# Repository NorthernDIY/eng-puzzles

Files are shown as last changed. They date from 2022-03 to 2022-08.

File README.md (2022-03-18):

# eng-puzzles
## ECE4600 G15 2021/2022 Capstone Project Code & Design Files
**As prepared by: Rowen Guncheon, Nicolas Hince, David Stewart, Lin Zhan on March 18/2022**

**For details of the software requirements for a particular portion of the project, please see the README.md file in the associated folder.**

# Summary of Hardware directory contents:
- **Hardware/MazeUnit**:  STL files for 3D printing a completed maze unit (with ESP32 Sidecar)
- **Hardware/PCB/ESP32_Subsystem**: PCB design files for the ESP32 Subsystem board that sits in the sidecar adjacent to the maze unit.
- **Hardware/PCB/POC**: PCB Design files for the Proof Of Concept board featuring ALS31313 Sensors
- **Hardware/PCB/Sensor_Block**:  PCB design files for the modular (2x2) Hall sensor boards that sit beneath the maze floor.
- **Hardware/Stylus**:  STL files for 3D printing a stylus unit.

# Summary of Software directory contents:
- **Software/AllPaths**:  Algorithm used for generating a library of paths from a given input maze.  (For use with future machine learning work)
- **Software/Main_Firmware**:  The main firmware that runs on the ESP32 SOC within the Maze Unit.
- **Software/PacketSimulator**: Python application that emulates ESP32 data packet format (Used during development)
- **Software/Addressing_Firmware**:  The initial Hall sensor address programming firmware that runs on the ESP32 SOC.
- **Software/Server**:  The required Python/Flask based server that runs on the Raspberry Pi (or other Linux system)
- **Software/Visualization**: The data visualization php script that reads data from the SQL database and overlays this information on a web page.  (place in /var/www/html)

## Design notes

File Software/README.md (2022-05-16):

# eng-puzzles
##Serious Games - Summer Research 2022
**by David Stewart**

**For details of the software requirements for a particular portion of the project, please see the README.md file in the associated folder.**
# Summary of Software directory contents:
- **Addressing_Firmware**:  The initial Hall sensor address programming firmware that runs on the ESP32 SOC.
- **PacketSimulator**: Python application that emulates ESP32 data packet format (Used during development)
- **Server**:  Python/Flask based server that runs on the Raspberry Pi (or other Linux system) and processing incoming data from the Maze Unit
- **Visualization**: The data visualization php script that reads data from the SQL database and overlays this information on a web page.  (place in /var/www/html)
- **Archive**: Older versions of code.
- - **AllPaths**:  Algorithm used for generating a library of paths from a given input maze.  (For use with future machine learning work)
- - **Main_Firmware**:  The main firmware that runs on the ESP32 SOC within the Maze Unit.

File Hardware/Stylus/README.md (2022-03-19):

# eng-puzzles
## ECE4600 G15 2021/2022 Capstone Project Code & Design Files
**As prepared by: Rowen Guncheon, Nicolas Hince, David Stewart, Lin Zhan on March 18/2022**

## Stylus STL Parts Info

### Software Used
- AutoDesk Inventor
- AutoDesk Print Studio

### Units
- Inches

### Parts Included
- Stylus main
- Stylus cap
- Stylus Insert

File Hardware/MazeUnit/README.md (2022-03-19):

# eng-puzzles
## ECE4600 G15 2021/2022 Capstone Project Code & Design Files
**As prepared by: Rowen Guncheon, Nicolas Hince, David Stewart, Lin Zhan on March 18/2022**

## Maze Unit STL Parts Info

### Software Used
- AutoDesk Inventor
- AutoDesk Print Studio

### Units
- Inches

### Parts Included
- Maze side A
- Maze side B
- Floor side A
- Floor side B
- Sidecar
- Sidecar cap

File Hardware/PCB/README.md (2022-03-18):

# eng-puzzles
## ECE4600 G15 2021/2022 Capstone Project Code & Design Files
**As prepared by: Rowen Guncheon, Nicolas Hince, David Stewart, Lin Zhan on March 18/2022**
## Hardware/PCB
- **ESP32_Subsystem**: PCB design files for the ESP32 Subsystem board that sits in the sidecar adjacent to the maze unit.
- **POC**: PCB Design files for the Proof Of Concept board featuring ALS31313 Sensors
- **Sensor_Block**:  PCB design files for the modular (2x2) Hall sensor boards that sit beneath the maze floor.

### Required Software
These files were exported from EasyEDA V 6.4.31 and should be importable to later versions.

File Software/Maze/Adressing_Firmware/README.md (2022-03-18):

# eng-puzzles
## ECE4600 G15 2021/2022 Capstone Project Code & Design Files
**As prepared by: Rowen Guncheon, Nicolas Hince, David Stewart, Lin Zhan on March 18/2022**

# Addressing_Firmware:
  The initial Hall sensor address programming firmware that runs on the ESP32 SOC.
  ### ***This must be run before uploading the main firmware file.***

## Requires:
- Arduino IDE v1.18 or newer

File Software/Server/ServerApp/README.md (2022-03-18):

# eng-puzzles
## ECE4600 G15 2021/2022 Capstone Project Code & Design Files
**As prepared by: Rowen Guncheon, Nicolas Hince, David Stewart, Lin Zhan on March 18/2022**

# Server:
Python/Flask based server that runs on the Raspberry Pi (or other Linux system) and processing incoming data from the Maze Unit. Contains both acceleromter filtering and the full positioning system.

This is basically glue that combines project elements.

## Requires:
- Python 3.7
- - With the following libraries: numpy, pymysql, scipy, flask, colorama, csv, math, time, os, json, sys

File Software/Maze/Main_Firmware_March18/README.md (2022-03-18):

# eng-puzzles
## ECE4600 G15 2021/2022 Capstone Project Code & Design Files
**As prepared by: Rowen Guncheon, Nicolas Hince, David Stewart, Lin Zhan on March 18/2022**

# Main_Firmware:  The main firmware that runs on the ESP32 SOC within the Maze Unit.

## Requires:
- Visual Studio Code:
  - With PlatformIO plugin installed
    - With ESP32 Board support package installed

- Libraries & Frameworks:
  - arduino-esp32 (https://github.com/espressif/arduino-esp32): Enables arduino framework to run on the ESP32 SOC.
  - ArduinoJSON (https://github.com/bblanchon/ArduinoJson): Enables serialization of data to JSON format.
  - SparkFun LIS2DH12 Arduino Library (https://github.com/sparkfun/SparkFun_LIS2DH12_Arduino_Library):  Provides support for the LIS2DH12 accelerometer.

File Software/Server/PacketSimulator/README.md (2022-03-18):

# eng-puzzles
## ECE4600 G15 2021/2022 Capstone Project Code & Design Files
**As prepared by: Rowen Guncheon, Nicolas Hince, David Stewart, Lin Zhan on March 18/2022**

# PacketSimulator:
Python application that emulates ESP32 data packet format (Used during development)

## Requires:
- Python 3.7
- - With the following libraries: json, random, requests, sys, datetime

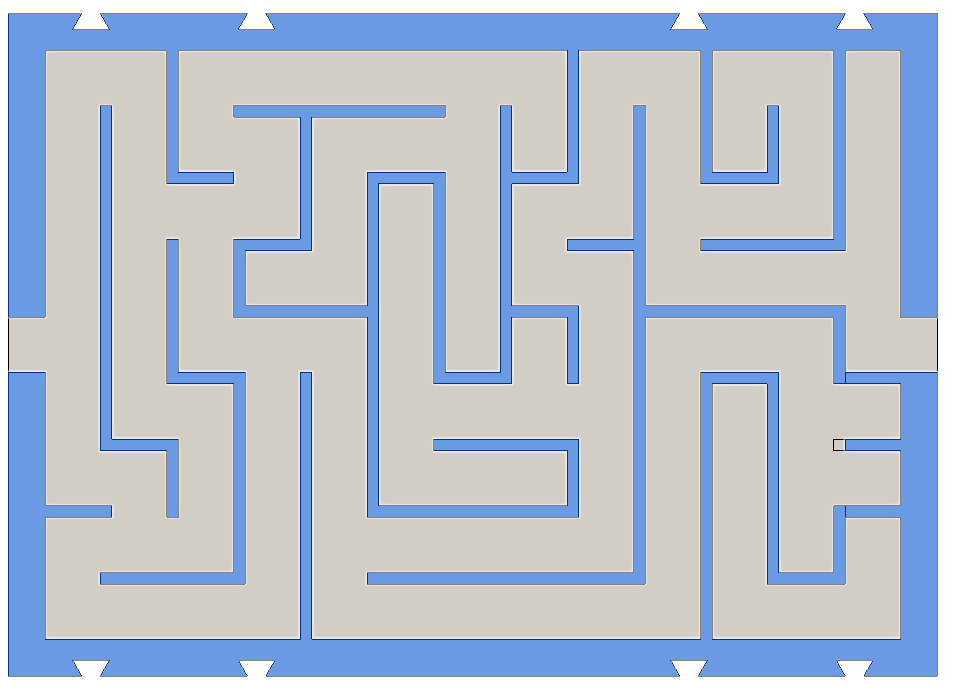
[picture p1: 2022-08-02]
Software/Server/ServerApp/Maze_top_down.png

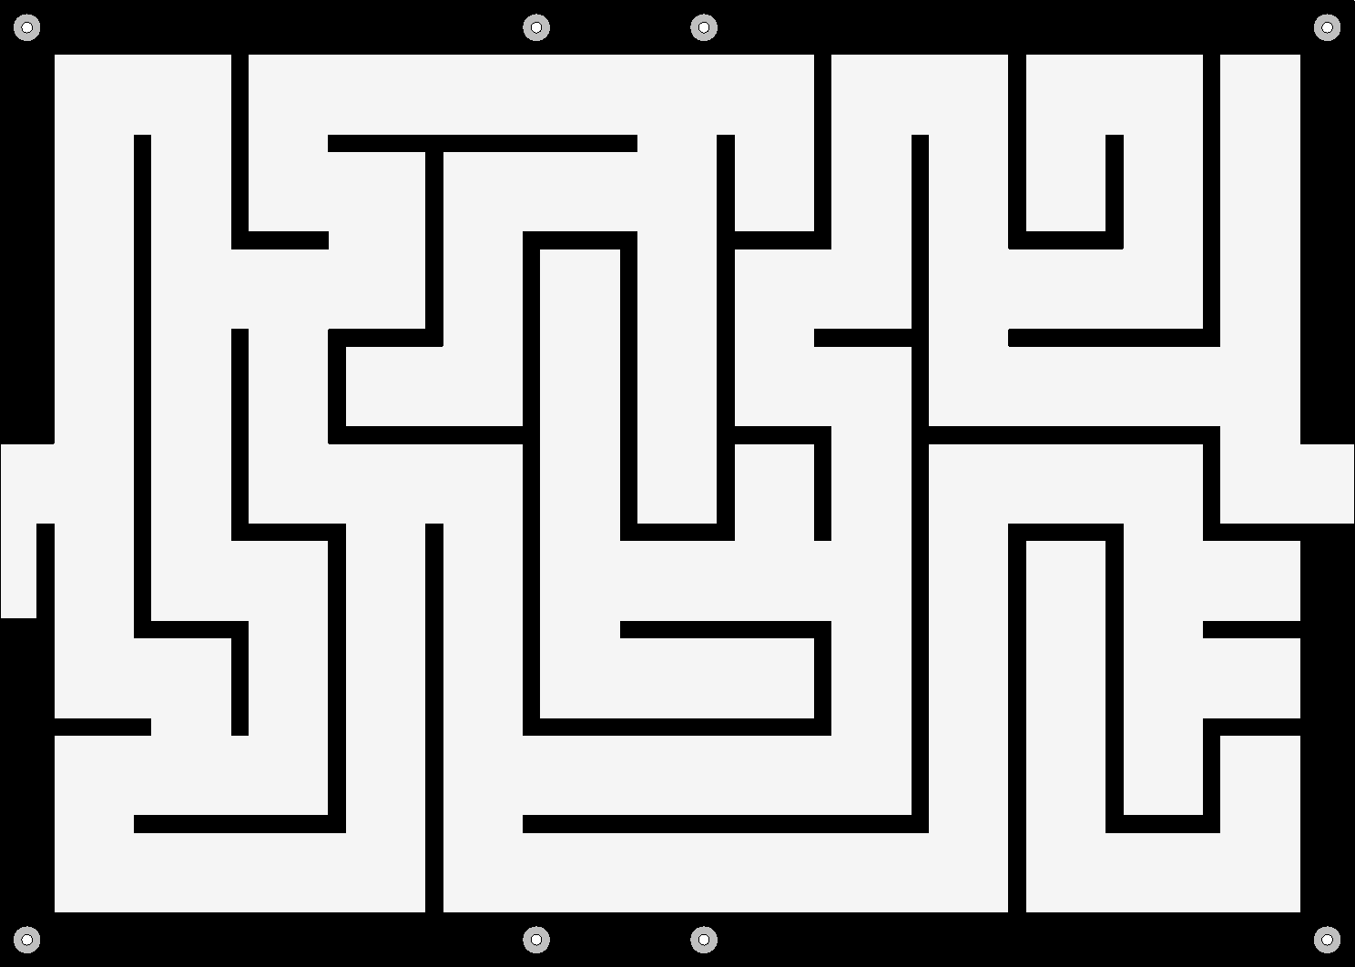
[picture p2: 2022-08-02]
Software/Server/ServerApp/MazeBWG.png

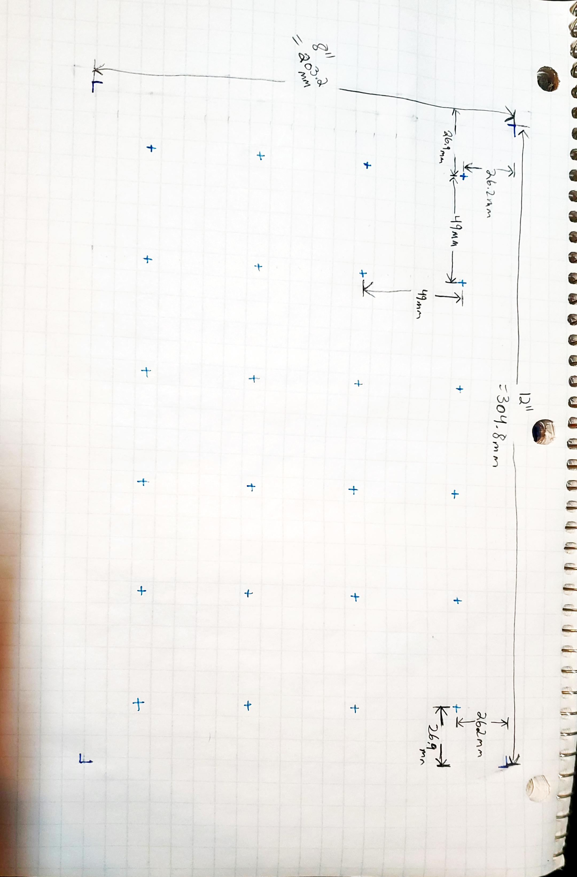
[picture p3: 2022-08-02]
Software/Server/ServerApp/MAzeSpacing.jpg

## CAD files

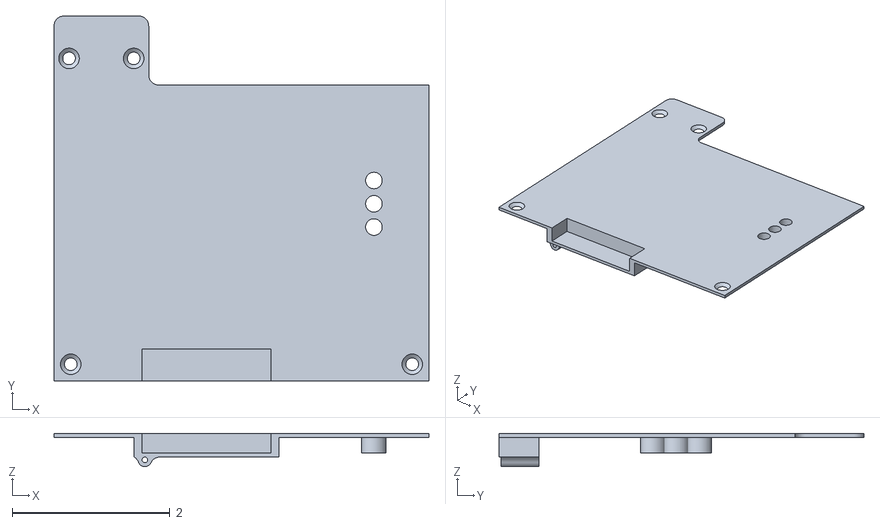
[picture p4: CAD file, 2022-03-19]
Hardware/MazeUnit/Sidecar Cap.stl
4.75 x 4.62 x 0.422

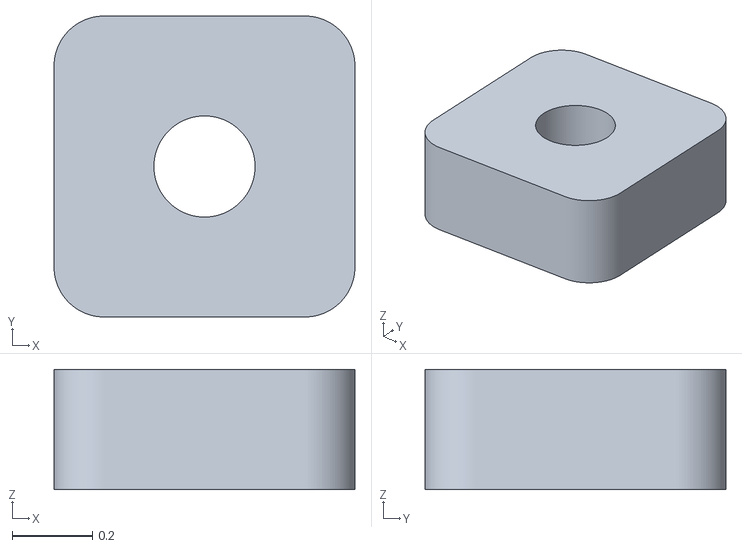
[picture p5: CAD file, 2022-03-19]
Hardware/Stylus/Stylus insert.stl
0.75 x 0.75 x 0.3

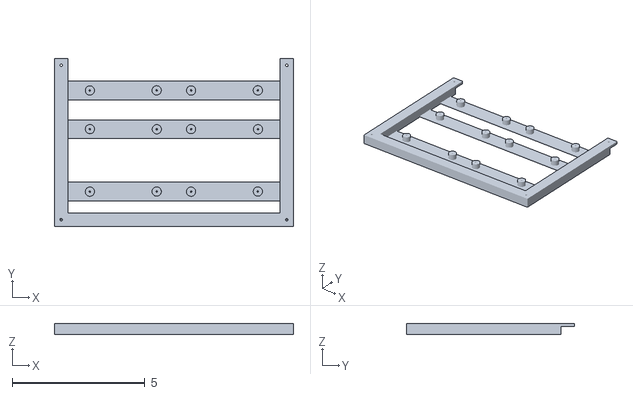
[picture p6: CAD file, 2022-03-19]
Hardware/MazeUnit/floorB.stl
9.00 x 6.31 x 0.423

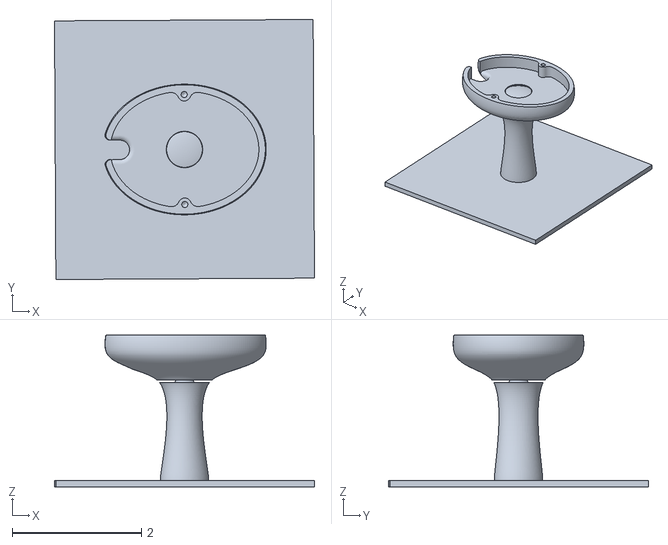
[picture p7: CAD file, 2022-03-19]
Hardware/Stylus/Stylus3.stl
4.02 x 4.02 x 2.35

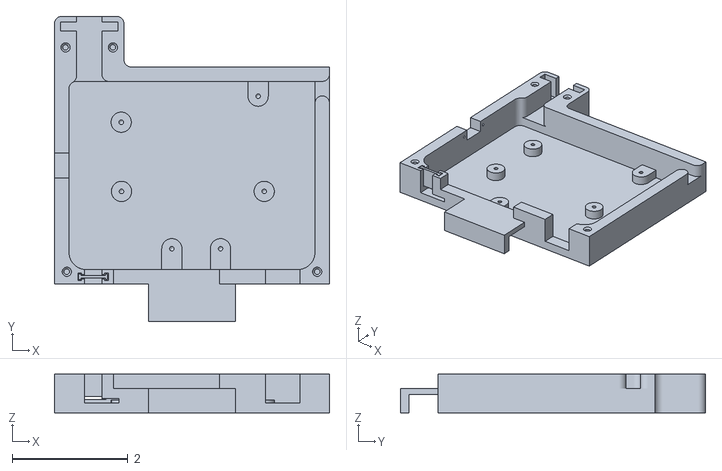
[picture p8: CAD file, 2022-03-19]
Hardware/MazeUnit/Sidecar.stl
4.75 x 5.27 x 0.673

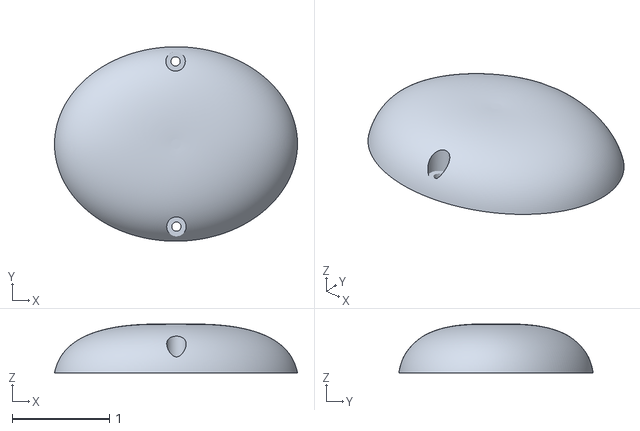
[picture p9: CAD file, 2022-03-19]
Hardware/Stylus/Stylus Cap.stl
2.50 x 2.00 x 0.503

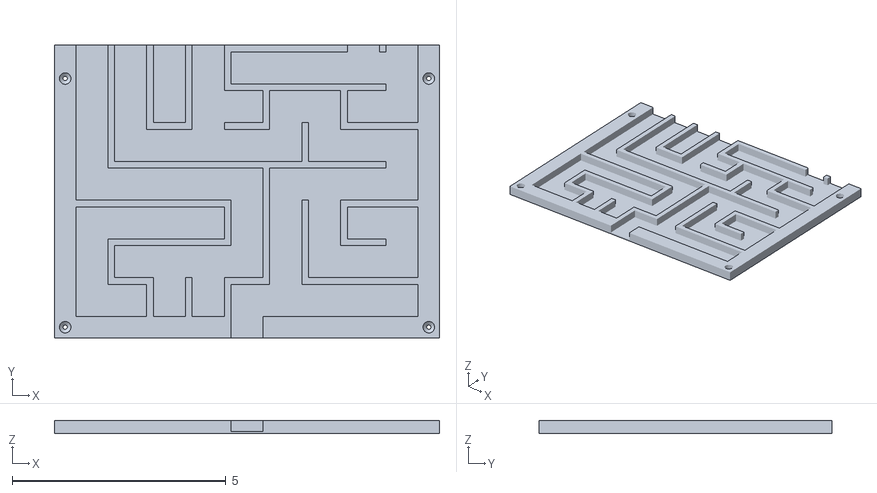
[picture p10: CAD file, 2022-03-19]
Hardware/MazeUnit/mazeB.stl
9.00 x 6.84 x 0.3

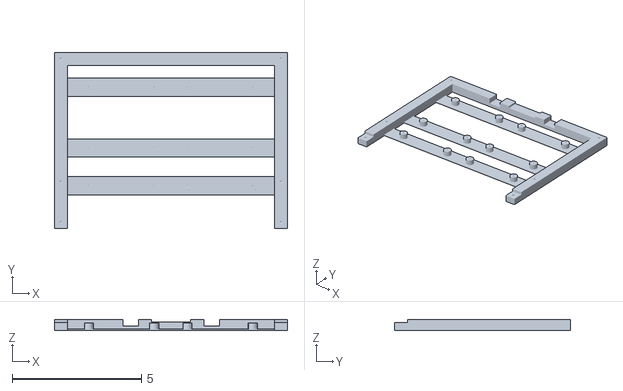
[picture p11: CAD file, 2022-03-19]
Hardware/MazeUnit/floorA.stl
9.00 x 6.81 x 0.423

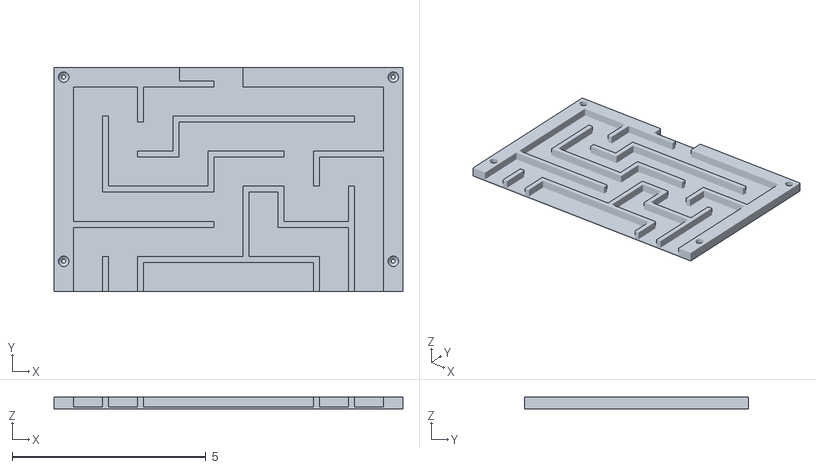
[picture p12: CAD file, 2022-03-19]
Hardware/MazeUnit/mazeA.stl
9.00 x 5.78 x 0.3

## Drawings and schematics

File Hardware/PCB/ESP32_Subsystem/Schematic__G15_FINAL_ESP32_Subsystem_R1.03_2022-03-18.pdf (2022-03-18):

### Only Use

1%

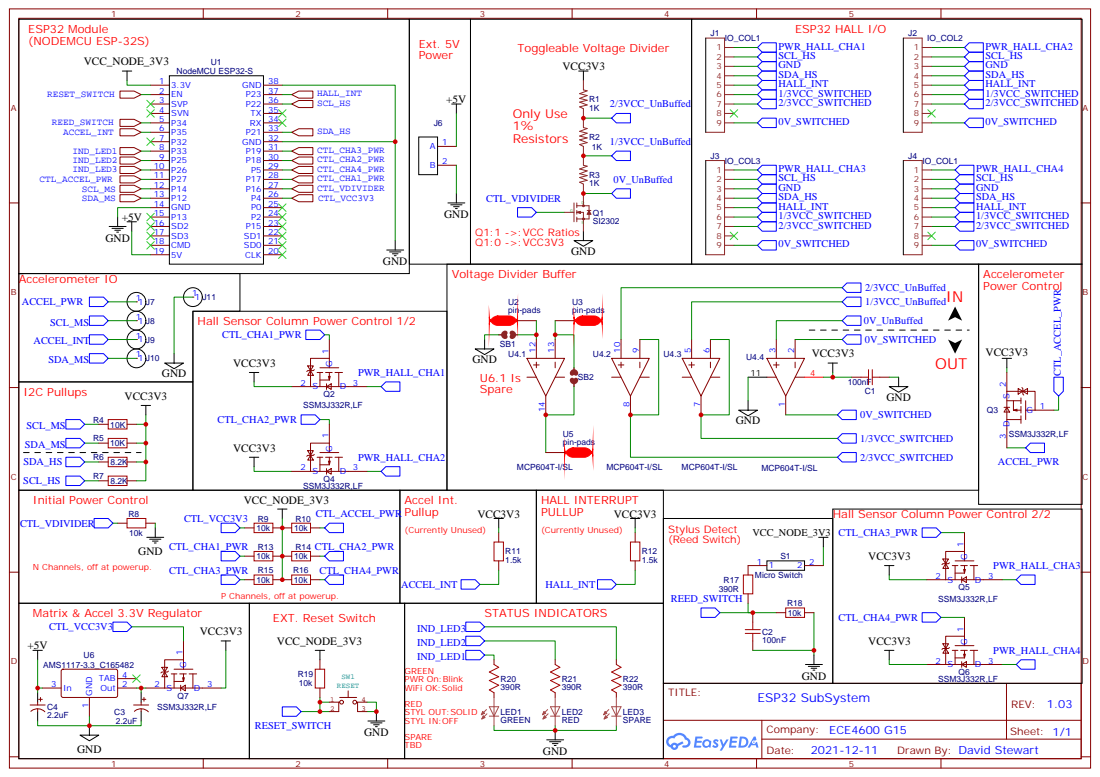
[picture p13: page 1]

Hall Sensor Column Power Control 1/2
CTL_CHA1_PWR

N Channels, off at powerup.

P Channels, off at powerup.

Drawn By: David Stewart

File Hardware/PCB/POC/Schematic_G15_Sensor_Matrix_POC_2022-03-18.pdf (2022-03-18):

## C20 Header-Female⁻2.54_1x8

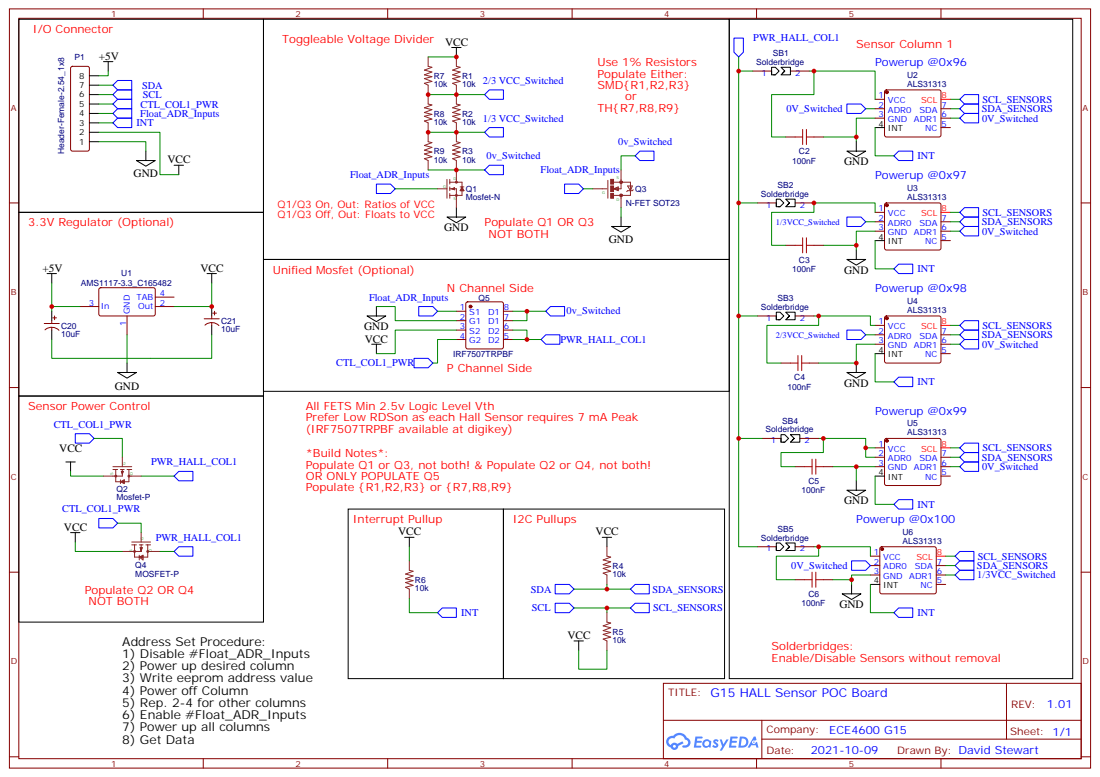
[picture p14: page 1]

Q1/Q3 On, Out: Ratios of VCC
Q1/Q3 Off, Out: Floats to VCC

All FETS Min 2.5v Logic Level Vth
Prefer Low RDSon as each Hall Sensor requires 7 mA Peak
(IRF7507TRPBF available at digikey)
*Build Notes*:
Populate Q1 or Q3, not both! & Populate Q2 or Q4, not both!
OR ONLY POPULATE Q5
Populate {R1,R2,R3} or {R7,R8,R9}

Address Set Procedure:
1) Disable #Float_ADR_Inputs
2) Power up desired column
3) Write eeprom address value
4) Power off Column
5) Rep. 2-4 for other columns
6) Enable #Float_ADR_Inputs
7) Power up all columns
8) Get Data

Solderbridges:
Enable/Disable Sensors without removal

TITLE: G15 HALL Sensor POC Board

Drawn By: David Stewart

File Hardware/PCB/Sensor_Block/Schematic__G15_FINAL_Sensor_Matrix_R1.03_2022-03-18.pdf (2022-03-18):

## Powerup @0x60

## Powerup @0x61

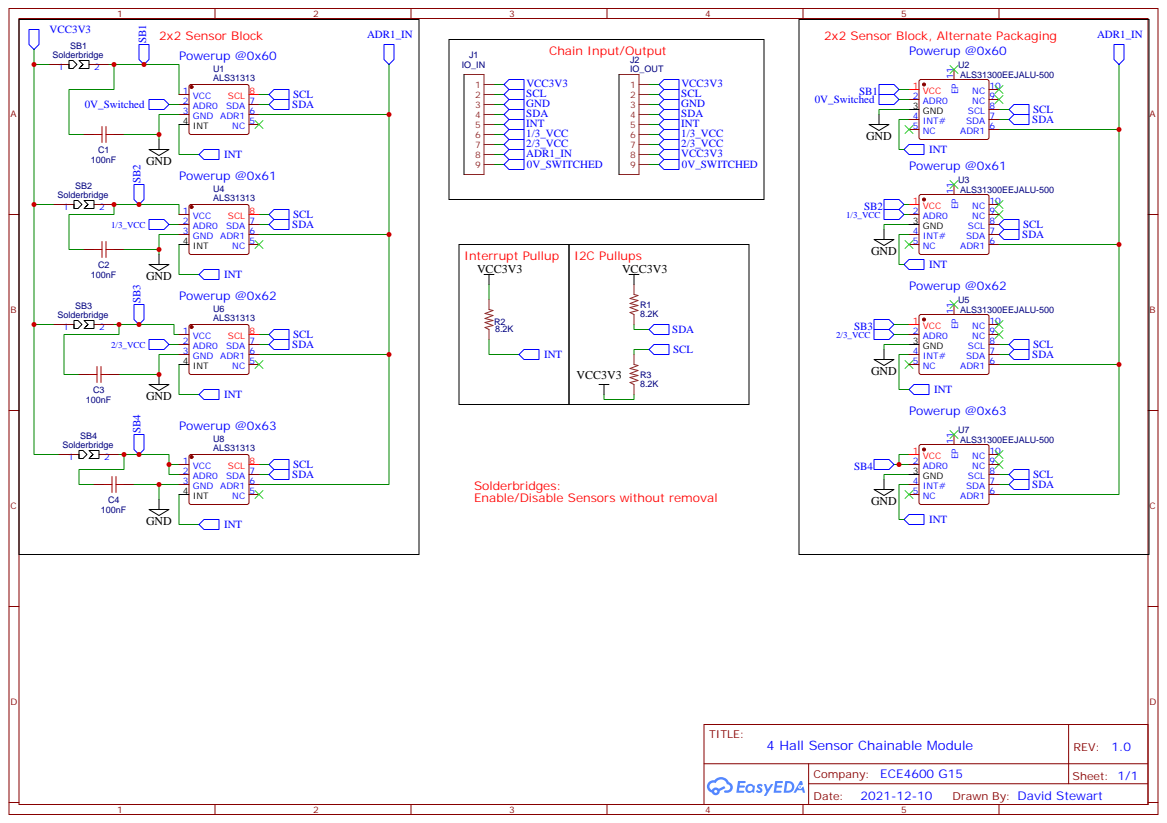
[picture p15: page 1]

Solderbridges:
Enable/Disable Sensors without removal

Drawn By: David Stewart

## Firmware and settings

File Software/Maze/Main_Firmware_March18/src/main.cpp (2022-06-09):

/*
 *  Written by David Stewart for ECE4600 G15 2021/2022
 *
 * 
 * 
 *  Portions of this code are based on VintLabs 3D-Hall available at https://github.com/vintlabs/3D-Hall
 *  Portions of this code are based on ALS31313 example code provided by Allegro Microsystems:
 *    Written by K. Robert Bate, Allegro MicroSystems, LLC.
 * 
 */

//Board:  ESP32 Nano32S
#define SIMULATE24SENSORS 0

#define VERSIONSTRING "V1.1-MAR-7-2022-EarlyDemoDay"

//Wifi Credentials
#define G15_SSID "ECE4600_G15"
#define G15_PASSWORD "ECE4600G15"

//Server Endpoints
#define G15_RESETURL "http://192.168.1.51:5000/r"//Just gives initial configuration data such as block size of data to be received during a session

#define G15_CALURL "http://192.168.1.51:5000/caldata"//Endpoint to post calibration data to, also initiates a new session

#define G15_HALLURL "http://192.168.1.51:5000/h"
#define G15_ACCURL "http://192.168.1.51:5000/a"

#define REED_SWITCH_ACTIVATION_TIME 200  //Switch debounce timeout

//Hall Sensor Matrix Properties
#define HALLAVERAGINGSAMPLES 40 //Number of samples in moving average
#define NUMSENSORS 24 //Should be 24 in final project
#define HALLSAMPPERIOD 10 //5.5ms is absolute min delay between samples
#define HALLREPORTTIME 50 //Report time interval
#define BLOCKSIZEHALL 1  //10 may have fragmentation issues that cause hiccups!

//Accelerometer Properties
#define ACCELSAMPPERIOD 10
#define BLOCKSIZEACCEL 4

//ALS31313 Hall Sensor parameters (from datasheet)
#define EEPROMDEFAULT 0b00000000000000000000001111100000
#define EEPROMADDRESSMASK 0b11111111111111100000001111111111
#define CAM_REGISTER 0x35
//#define CAM_KEY 0x2C41354 //Was incorrect in example code //ALS31313 Sensors
#define CAM_KEY 0x2C413534 //ALS31300 Sensors

//MCPWM LED CONTROL Macros - Too short to need a seperate function, too long to type out in full each time
#define haltGreenLed() MCPWM0.timer[0].mode.start=0
#define solidGreenLed() mcpwm_set_signal_high(MCPWM_UNIT_0,MCPWM_TIMER_0, MCPWM_OPR_A)
#define offGreenLed() mcpwm_set_signal_low(MCPWM_UNIT_0,MCPWM_TIMER_0, MCPWM_OPR_A)

#define haltRedLed() MCPWM1.timer[0].mode.start=0
#define solidRedLed() mcpwm_set_signal_high(MCPWM_UNIT_1,MCPWM_TIMER_0, MCPWM_OPR_A)
#define offRedLed() mcpwm_set_signal_low(MCPWM_UNIT_1,MCPWM_TIMER_0, MCPWM_OPR_A)

//To speed up final project computational speed, uncomment the following!
//This will require additional Flash/Ram, but can provide substantial speed increases.
//#pragma GCC optimize ("-O2")

//Libraries required
#include <Arduino.h>
#include <Wire.h> //Provides I2C
#include <WiFi.h>
#include <HTTPClient.h> //Used for HTTP Comms to server
#include <ArduinoJson.h> //Data sent is serialized in JSON, this library gives us easy access to that data type
#include "SparkFun_LIS2DH12.h"//Accelerometer embedded in stylus for tremor detection

//Libraries to enable Output of LOW FREQ PWM Using MCPWM Peripheral
#include "soc/mcpwm_reg.h"
#include "soc/mcpwm_struct.h"
#include "driver/mcpwm.h"

//Actual C code files C:\Users\---username---\.platformio\packages\framework-espidf\components\driver
#include "driver/i2c.h" //Needed to allow use of I2C peripheral settings to actually reach 1MHz!
TwoWire I2C_HS = TwoWire(0);//HS I2C (Hall Sensors)
TwoWire I2C_MS = TwoWire(1);//MS I2C (Accelerometer)

SPARKFUN_LIS2DH12 accel;
#define ACCEL_ADDRESS 0x19

const char* ssid = G15_SSID;
const char* password = G15_PASSWORD;
String hallServerName = G15_HALLURL;
String accelServerName = G15_ACCURL;
String resetServerName = G15_RESETURL;
//String sessionStartServerName = G15_SESSIONSTARTURL;
String caldataServerName = G15_CALURL;

// Return values of endTransmission in the Wire library
#define kNOERROR 0
#define kDATATOOLONGERROR 1
#define kRECEIVEDNACKONADDRESSERROR 2
#define kRECEIVEDNACKONDATAERROR 3
#define kOTHERERROR 4

//Debugging Things
int skipCountHall = 0;  // Keep track of number of times through main loop without reporting
int skipCountAccel = 0;  // Keep track of number of times through main loop without reporting


//Moving Average Struct to store Hall sensor readings
typedef struct{
  uint8_t sampIndex;
  int sampX[HALLAVERAGINGSAMPLES];
  int sampY[HALLAVERAGINGSAMPLES];
  int sampZ[HALLAVERAGINGSAMPLES];
  float avgX,avgY,avgZ;//Stored as int using multiplier 10000
  int totX,totY,totZ;
  uint8_t address; 
} MASensor;

MASensor sensors[NUMSENSORS];

float BiotSavartCalConstantX = 0.0;
float BiotSavartCalConstantY = 0.0;
float BiotSavartCalConstantZ = 0.0;
//Each packet has one T = Key, increments by whatever hallBlockSize*sampTime(50mS) or accelBlockSize*sampTime(10ms) is
int hallTimeStamp = 0;
int accelTimeStamp = 0;

//Keeps track of current time stamp within a bundled packet (increments and resets at hallBlockSize/accelBlockSize)
int hallPacketIndex = 0;
int accelPacketIndex = 0;

//Number of matrix scans to bundle into a packet
const uint8_t hallBlockSize = BLOCKSIZEHALL;
const uint8_t accelBlockSize = BLOCKSIZEACCEL;

//Json stores hallBlockSize sample periods worth of data.
DynamicJsonDocument hallDoc((1536 + 64) * hallBlockSize);//TUNING - Recalculate packet size based on new Hx# values

JsonArray Hx[hallBlockSize];
JsonArray Hy[hallBlockSize];
JsonArray Hz[hallBlockSize];

JsonArray Ax,Ay,Az;

WiFiClient client;

//We generate these once below instead of sprintf'ing our way to new strings each packet
//This saves a lot of time
char HxLabel[hallBlockSize][6];
char HyLabel[hallBlockSize][6];
char HzLabel[hallBlockSize][6];

//Json stores accelBlockSize sample periods worth of data
DynamicJsonDocument accelDoc((64 + 4) * accelBlockSize);//TUNING - Recalculate packet size based on new Ax# values

//Tracking timestamps of last sample, and last report.  TODO - CONSIDER Move to Timer interrupt based sampling
unsigned long loopStartTime, lastHallSampleTime, lastHallReportTime, lastAccelSampleTime, lastAccelReportTime;

//This is the power up addresses of the sensors when using the voltage divider inputs to ADR0/1
//Repeated for convenience across 2 channels
uint8_t FactoryPowerUpAddresses[NUMSENSORS] = {96,97,98,99,100,101,102,103,104,105,106,107,96,97,98,99,100,101,102,103,104,105,106,107};

//Addresses of hall sensors if they have been programmed
const int sensorAddresses[] = {12,22,11,21,14,24,13,23,16,26,15,25,32,42,31,41,34,44,33,43,36,46,35,45};
const int calSensorAddress = 31;
const int calSensorIndexLocation = 14;//Location in the array above...used to reference sensor data for BiotSavart Const Calculation
//PIN INFORMATION
//N-Channel disconnects ground from voltage divider circuit.  Causes ADR0/1 to float to VCC.  HIGH = Divider Enabled, LOW = Divider Disabled (Floats to VCC)
#define CTL_VDIVIDER 16

//P-Channel VCC3V3 High Side Switch for everything but the esp32.  Disconnects: VDivider, Vdivider Op Amp Buffer, Accelerometer, Hall Sensors.
#define _CTL_VCC3V3 4

//P-Channel high side switch for sensor channel power.  LOW = Sensor power enabled, HIGH = Sensor power disabled
#define _CTL_CHA1_PWR 17
#define _CTL_CHA2_PWR 18
#define _CTL_CHA3_PWR 19//Unused
#define _CTL_CHA4_PWR 5//Unused

//P-Channel high side switch for accelerometer power.  LOW = Sensor power enabled, HIGH = Sensor power disabled
#define _CTL_ACCEL_PWR 27

//Status LEDS
#define IND_LED1 33//Green
#define IND_LED2 25//Red
#define IND_LED3 26//Yellow

//Primary I2C Bus (1 MHz)
#define SCL_HS 22
#define SDA_HS 21

//Secondary I2C Bus (400 KHz)
#define SCL_MS 14
#define SDA_MS 12

//Reed Switch, lets us switch from waiting to runtime mode
#define REED_SWITCH 34

//Sensors interrupts, probably will be unused
#define ACCEL_INT 35
#define HALL_INT 23

//Function prototypes
void powerOffSensors();
void powerOnSensors_useEEPROMAddressses();
void powerOnSensors_useDividerAddresses();

void initSensor(uint8_t index);
void enterCam(uint8_t busAddress, uint32_t magicKey);
void setup();
void IRAM_ATTR loop();
void IRAM_ATTR sampleAccelerometer();
void IRAM_ATTR scanHallMatrix();
void IRAM_ATTR buildSendHallPacket(uint32_t loopStartTime);
void IRAM_ATTR buildSendAccelPacket(uint32_t loopStartTime);
void IRAM_ATTR readALS31300ADC(uint8_t index);
uint16_t read(int busAddress, uint8_t address, uint32_t& value);
uint16_t write(int busAddress, uint8_t address, uint32_t value);
long IRAM_ATTR SignExtendBitfield(uint32_t data, int width);
void setupNoCPULEDBlink(uint8_t pin1, uint8_t pin2); //Setup the MCPWM Peripheral to control led blinking
void blinkRedLed();
void blinkGreenLed();
void initI2CBusses();
void beginSession();
void sendCalData();
void clearAccelPacketBuffer();
void clearHallPacketBuffer();

//
// setup
//
// Initializes the Wire library for I2C communications,
// Serial for displaying the results and error messages,
// the hardware and variables to blink the LED,
// and sets the ALS31300 into customer access mode.
//
void setup()
{
  //Setup pin directions   
  pinMode(_CTL_VCC3V3, OUTPUT);
  pinMode(_CTL_ACCEL_PWR, OUTPUT);
  pinMode(CTL_VDIVIDER, OUTPUT);
  pinMode(_CTL_CHA1_PWR, OUTPUT);
  pinMode(_CTL_CHA2_PWR, OUTPUT);
  pinMode(_CTL_CHA3_PWR, OUTPUT);
  pinMode(_CTL_CHA4_PWR, OUTPUT);
  pinMode(IND_LED1,OUTPUT);  //Green LED
  pinMode(IND_LED2, OUTPUT); //Red LED
  pinMode(IND_LED3, OUTPUT); //Yellow LED
  pinMode(REED_SWITCH, INPUT);

  digitalWrite(IND_LED1, HIGH);
  digitalWrite(IND_LED2, HIGH);
  digitalWrite(IND_LED3, HIGH);

 //Turn on main power and Channels 1 & 2 - Divider off = assume eeprom is setup already
  digitalWrite(_CTL_VCC3V3,LOW); //3v3 on
  digitalWrite(CTL_VDIVIDER, LOW);
  delay(10);
  digitalWrite(_CTL_CHA1_PWR, LOW);//CHA1 on
  digitalWrite(_CTL_CHA2_PWR, LOW);//CHA2 On
  digitalWrite(_CTL_ACCEL_PWR, LOW);//Accel On
  delay(250);

  digitalWrite(IND_LED1, LOW);
  digitalWrite(IND_LED2, LOW);
  digitalWrite(IND_LED3, LOW);
  
  //setupNoCPULEDBlink(IND_LED1, IND_LED2); //Setup the MCPWM peripherals to handle low speed led blinking
  //blinkGreenLed();

  // Initialize the serial port
  Serial.begin(230400);
  int freq = ESP.getCpuFreqMHz();
  Serial.print("\nSystem Frequency: ");
  Serial.println(freq);
  Serial.print("Connecting to WiFi:");
  Serial.print(ssid);
  
  WiFi.begin(ssid, password);
  while(WiFi.status() != WL_CONNECTED){
    delay(250);
    Serial.print(".");
  }
  Serial.print("Connected!\nLocal IP: ");
  Serial.println(WiFi.localIP());
  
  initI2CBusses(); // Initialize the I2C communication ports

  //Initialize each Hall sensor -- Enters CAM mode and sets up Full Loop Register 
  for (uint8_t index = 0; index<NUMSENSORS; index++){
    initSensor(index);
  }

  //Initialize Accelerometer
  accel.begin(ACCEL_ADDRESS, I2C_MS);
  accel.setDataRate(LIS2DH12_ODR_400Hz);
  //accel.setSensitivity();

  //Development Info
  Serial.printf("SETTINGS:,SamplePeriod:,%dms,ReportRate:,%dms,NumSensors:,%d,AvgSamples:,%d\n", HALLSAMPPERIOD,HALLREPORTTIME,NUMSENSORS,HALLAVERAGINGSAMPLES);

  //TODO - Move to separate function.  Nothing below is a variable so no need to pass any data; Return value can be httpResponseCode  
  //Send reset to server along with block size information + other interesting things
  HTTPClient http;
  StaticJsonDocument<2048> startDoc;
  startDoc["Version"] = VERSIONSTRING;
  //startDoc["HallID"]="ALS31313KLEATR-500";
  startDoc["HallID"]="ALS31300EEJASR-500";
  startDoc["H_Samp_Int"]=HALLREPORTTIME;//This is the sample rate that we sample the AVERAGE, the actual sample rate is higher
  startDoc["NumSens"] = NUMSENSORS;
  startDoc["SIMULATED24"]= SIMULATE24SENSORS;
  startDoc["Hbs"] = hallBlockSize;
  startDoc["AccelID"] = "LIS2DH12";
  startDoc["A_Samp_Int"] = ACCELSAMPPERIOD;
  startDoc["Abs"] = accelBlockSize;
  startDoc["Core Freq"]= freq;
  http.begin(client, resetServerName);
  http.addHeader("Content-Type", "application/json");
  String stringifiedJson;
  serializeJson(startDoc, stringifiedJson);
  int httpResponseCode =http.POST(stringifiedJson);
  uint8_t retryInitialPostCount = 0;
  while (httpResponseCode!=200 && retryInitialPostCount<20){
    httpResponseCode = http.POST(stringifiedJson);
    delay(500);
    retryInitialPostCount++;
  }
  if (httpResponseCode != 200){
    //offGreenLed();
    //blinkRedLed();
    Serial.println("Unable to reach Raspberry Pi Server, Make sure it's running!\nHalting!");
    while(1);
  }
  http.end();
  startDoc.clear();
  
  //Initialize Global variables used in session loop //TODO - Move to local variables .....if reasonable to do so.  Likely to need lots of pass by value function calls...
  lastHallSampleTime = 0;
  lastHallReportTime = 0;
  lastAccelSampleTime = 0;
  lastAccelReportTime = 0;
  
  //Generate our Hall Sensor Keys in advance, avoids sprintf every packet (speedup!)
  for (int index = 0; index<hallBlockSize;index++){
    sprintf(HxLabel[index], "Hx%u", index);
    sprintf(HyLabel[index], "Hy%u", index);
    sprintf(HzLabel[index], "Hz%u", index);
  }
  
  //For the BiotSavart Constant
  digitalWrite(IND_LED3, HIGH); //Turn on Yellow LED, Indicate waiting!
  while(!digitalRead(REED_SWITCH)); //Wait for reed switch to be in place before gathering data
  uint32_t sTime = millis();
  uint32_t cTime=0;
  int count = 0;
  while(count<50){
    cTime = millis();  
    if((cTime - sTime)>=5){//We can read this faster than 6ms since it's only one sensor.
      sTime = cTime;
      readALS31300ADC(calSensorIndexLocation);
      count++;
    }
  }
  BiotSavartCalConstantX = sensors[calSensorIndexLocation].avgX;
  BiotSavartCalConstantY = sensors[calSensorIndexLocation].avgY;
  BiotSavartCalConstantZ = sensors[calSensorIndexLocation].avgZ;
  digitalWrite(IND_LED3, LOW);
  
  Serial.println("G15 Instrumented Puzzle Initialized...\nReady state starts in 1 Sec");
  delay(1000);
  //solidGreenLed();//Everything is ready to record data!
}

//Main loop just waits for reed switch to activate
void loop()
{
  uint32_t tTime = millis();
  bool Triggered = false;
  while(1){
    if (!digitalRead(REED_SWITCH) && !Triggered){
      Triggered = true;
      tTime = millis();
    }else if(digitalRead(REED_SWITCH)) {
      Triggered = false;
      tTime = 0;
    }
    if (Triggered && ((millis() - tTime)>=REED_SWITCH_ACTIVATION_TIME)){
      beginSession();
    }
  }//End of While(1)
}//End of Loop()

//Gathers and sends CalData before 
void IRAM_ATTR beginSession(){
  hallTimeStamp = 0;
  accelTimeStamp = 0;
  lastHallSampleTime = 0;
  lastHallReportTime = 0;
  lastAccelSampleTime = 0;
  lastAccelReportTime = 0;
 
  skipCountHall =0;//Reset the skip counter
  hallPacketIndex = 0; //Reset the packet index for our next data block
  skipCountAccel =0;
  accelPacketIndex = 0;
  //RESET packet indexes

  sendCalData();//This could change if for example, maze is moved after powerup
  //Populate the initial time stamps, avoids repeated if logic in buildSendPacket
  hallDoc["T"] = hallTimeStamp;
  accelDoc["T"] =accelTimeStamp;
  //To avoid blank first Accel packet
  Ax = accelDoc.createNestedArray("X");
  Ay = accelDoc.createNestedArray("Y");
  Az = accelDoc.createNestedArray("Z");
  uint32_t tTime = 0;
  //blinkRedLed();
  bool Active = true;//state variable toggled by reed switch
  
  while(Active){//The main data collection loop
      loopStartTime = millis();
      //Sample accelerometer if it is time to do so again.
      if ((loopStartTime - lastAccelSampleTime)>ACCELSAMPPERIOD){
        buildSendAccelPacket(loopStartTime);
        lastAccelSampleTime = loopStartTime;//Update the last SAMPLED time
      }else{
        skipCountAccel++;//Wasn't time so increment the skipped counter
      }
      
      loopStartTime = millis();//Regrab the time as the above might actually take time to complete!
      
      //Sample Hall Matrix if it is time to do so again.
      if ((loopStartTime-lastHallSampleTime)>HALLSAMPPERIOD){
        lastHallSampleTime = loopStartTime; //update the last SAMPLED time
        scanHallMatrix();
        //Serial.printf("loopStart: %d\tlastHallSamp: %d\tlastHallRep: %d\n",loopStartTime, lastHallSampleTime, lastHallReportTime);
        if ((loopStartTime-lastHallReportTime)>(HALLREPORTTIME))buildSendHallPacket(loopStartTime);
      }else{
        skipCountHall++; //Wasn't time so increment skipped counter
      }
      if ((loopStartTime - tTime)>=1000){
        if (digitalRead(REED_SWITCH)&&hallPacketIndex){
          Active = false;
          tTime = loopStartTime;
          offRedLed();
          clearHallPacketBuffer();
          clearAccelPacketBuffer();
        }else (tTime = loopStartTime); //Forces sessions to be increments of 1 Second long
      }
    }//End of While(Active)
}


/*  sendCalData
*     Sends prefilled moving average sample data for all sensors to the server
*     Data used for position tracking algorithm and server uses this packet to indicate a new session has started.
*/
void sendCalData(){
  //solidRedLed();
  uint32_t sTimer = millis();
  int count = 0;
  //Scan the Hall Matrix HALLAVERAGINGSAMPLES times, every HALLSAMPPERIOD milliseconds
  //Basically prefill the moving average.
  while(count<HALLAVERAGINGSAMPLES){
    if ((millis()-sTimer) >=HALLSAMPPERIOD){
      sTimer = millis();
      scanHallMatrix();
      count++;
    }     
   }
  HTTPClient http;
  //StaticJsonDocument<2560> calDoc;
  DynamicJsonDocument calDoc(2816);
  calDoc["BSX"] = BiotSavartCalConstantX;
  calDoc["BSY"] = BiotSavartCalConstantY;
  calDoc["BSZ"] = BiotSavartCalConstantZ;

  JsonArray calX = calDoc.createNestedArray("H_CAL_X");
  JsonArray calY = calDoc.createNestedArray("H_CAL_Y");
  JsonArray calZ = calDoc.createNestedArray("H_CAL_Z");
  for (int index = 0; index<NUMSENSORS;index++){
      calX.add(sensors[index].avgX);
      calY.add(sensors[index].avgY);
      calZ.add(sensors[index].avgZ);
  }

  http.begin(client, caldataServerName);
  http.addHeader("Content-Type", "application/json");
  String stringifiedJson;
  serializeJson(calDoc, stringifiedJson);
  //Send it.
  int httpResponseCode = http.POST(stringifiedJson);
  http.end();
  //Serial.println("New Session!...Cal Data Sent");
  //Serial.println(stringifiedJson);
  calDoc.clear();
}

void IRAM_ATTR buildSendAccelPacket(uint32_t loopStartTime){

    //if the packet index is the size of our blocksize, then it is time to transmit
    //at T=0, there are no samples to report hence, accelTimeStamp>accelBlockSize
    if ((accelPacketIndex%accelBlockSize)==0  && accelPacketIndex>0){
      HTTPClient http;
      accelDoc["SC"] = skipCountAccel; //Performance metrics, how many main loops we skipped without sampling.
      accelPacketIndex = 0;//reset the sample index within the packet.
            
      http.begin(client, accelServerName);
      http.addHeader("Content-Type", "application/json");//Might not actually need this!
      
      //Convert the json document to a string for transmission
      String stringifiedJson;
      serializeJson(accelDoc, stringifiedJson);
      
      //Send it
      int httpResponseCode = http.POST(stringifiedJson);//TODO - Use response code to indicate issues!!!
      http.end();
      
      clearAccelPacketBuffer();
    }else{
      Ax.add(accel.getX());
      Ay.add(accel.getY());
      Az.add(accel.getZ());
      accelPacketIndex++;
    }
}

void IRAM_ATTR clearAccelPacketBuffer(){

      accelPacketIndex = 0;//reset the sample index within the packet.
      accelDoc.clear();//Clear out old information in the Json Structure.
      skipCountAccel=0;//Reset the skip counter
      accelTimeStamp +=(accelBlockSize*ACCELSAMPPERIOD);//Increment the timestamp by the block size
      accelDoc["T"] =  accelTimeStamp;//Prepend the timestamp of the first next sample to the JSON document
      lastAccelReportTime=loopStartTime;//Record the last Reported Time
      
      //Recreate the nested arrays for next time
      Ax = accelDoc.createNestedArray("X");
      Ay = accelDoc.createNestedArray("Y");
      Az = accelDoc.createNestedArray("Z");
}

void IRAM_ATTR clearHallPacketBuffer(){
  hallDoc.clear();
  skipCountHall =0;//Reset the skip counter
  hallPacketIndex = 0; //Reset the packet index for our next data block
  hallTimeStamp +=(hallBlockSize*HALLREPORTTIME); //Increment the timestamp by the blocksize
  hallDoc["T"] =  hallTimeStamp; //Set the starting timestamp of the next packet
}
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

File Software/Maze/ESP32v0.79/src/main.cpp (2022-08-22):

/*
 *  Portions of this code are bsed on "Example code for reading an ALS31313 3D Hall Effect Sensor on ESP32 in Arduino environment." by VintLabs 
 *  which in tern is based on code provided by Allegro Microsystems:
 *      Example source code for an Arduino to show how to communicate with an Allegro ALS31300
 *          Written by K. Robert Bate, Allegro MicroSystems, LLC.*    
 *    
 *    ECE4600 G15 Modified by David Stewart Oct 26/2021
 *      Added Power control stuff
 *    Modified by David Stewart Nov 11/2021
 *      Major rewrite of ReadADC function to accomodate use of Structs to hold sensor and moving average data.  
 *      Addition of sensor init routine
 *      Added independent report period interval, in addition to existing sample period interval.
 *      Expanded # sensor read up to 5
 */

//Board:  ESP32 Nano32

//To speed up final project computational speed, uncomment the following!
//This will require additional Flash/Ram, but can provide substantial speed increases.
#pragma GCC optimize ("-O2")

//Libraries required
#include <Arduino.h>
#include <Wire.h> //Provides I2C
#include <WiFi.h>
#include <WiFiUdp.h>
#include <ArduinoJson.h> //Data sent is serialized in MSGPACK, this library gives us easy access to that data type
#include "SparkFun_LIS2DH12.h"//Accelerometer for tremor identification
//#include <esp_task_wdt.h>
#include <esp_wifi.h>

#include "SSD1306Ascii.h"
#include "SSD1306AsciiWire.h"

#define VERSIONSTRING "v0.89" //Firmware Version String
//WiFi credentials
#define G15_SSID "AMazeThing"
#define G15_PASSWORD "hn7P8Egh"

#define MSGBUFFERSIZE 1500 //Size of char buffers to serialze msgpack data into (2x buffers)

#define SERVERCHECKTIME 3000 //Check server alive every nnnn/1000 seconds
#define HOME_SWITCH_ACTIVATION_TIME 300 //Time to wait after inital switch open before starting a new session (Part of debounce)
#define SPINNERTASKDELAY 500 //Time between spins for the user feedback spinner task

#define DBGSERIAL 1 //Output various information over serial  (Used during parameter tuning)
#define INITSERIAL 1
//Hall Sensor Matrix Properties
//#define HALLAVERAGINGSAMPLES 20 //Number of samples in moving average
#define HALLAVERAGINGSAMPLES_MAX 60  //Max size of moving averange ring buffer
#define NUMSENSORS 24 //Should be 24 in final project

//Once total msgpack size exceeds about 1470 bytes, packets are fragmented and then the system breaks!
#define BLOCKSIZEHALL 15 //17 is about the maximum we can go before fragmentation will start to become an issue - MSGBUFFERSIZE (based on MTU) is the limitation else we start spanning packets

uint16_t HALLAVERAGINGSAMPLES = 20;
uint16_t HALLSAMPPERIOD = 25;
uint16_t HALLREPORTTIME = 200;
uint16_t ACCELSAMPPERIOD = 40;
//Accelerometer Properties
//#define ACCELSAMPPERIOD 40// 1/(40/1000) = 25 Hz Sample Rate --> Nyquist 20Hz
#define BLOCKSIZEACCEL 150

//ALS31313 Hall Sensor parameters (from datasheet)
#define EEPROMDEFAULT     0b00000000000000000000001111100000
#define EEPROMADDRESSMASK 0b11111111111111100000001111111111
#define CAM_REGISTER 0x35
//#define CAM_KEY 0x2C41354 //Was incorrect in example code //ALS31313 Sensors
#define CAM_KEY 0x2C413534 //ALS31300 Sensors

//Server Properties to look for (and what port to listen for service broadcast
#define MINSERVERVER 89
#define SERVICEREQUIRED "MAZE_SERVER"
#define SERVICEBROADCASTPORT 1998
//Keys used in service broadcast message
#define KEY_SERVICETYPE "SVC"
#define KEY_SERVICEVER "VER"
#define KEY_STARTPORT "PORT"

//MSGPACK (JSONDOC) KEYS
#define KEY_HALLTIME "TH" //Presence of key when sent to server indicates Hall packet (this is the time stamp)
#define KEY_HALLDATA "D"
#define KEY_ACCELTIME "TA"//Presence of key when sent to server indicates Accel packet (this is the time stamp)
#define KEY_ENDSESSION "Bye"//Sent to server to close session
#define KEY_STARTSESSION "Hey"//Sent to server to start a new session
#define KEY_FWVER "FWV"
#define KEY_BIOSAV "B"//Run time calibration constant sent at start of session
//#define KEY_BIOSAVX "BSX"//Run time calibration constant sent at start of session
//#define KEY_BIOSAVY "BSY"//Run time calibration constant sent at start of session
//#define KEY_BIOSAVZ "BSZ"//Run time calibration constant sent at start of session
//#define KEY_HCALX "H_CAL_X"//Run time baseline noise data sent at start of session
//#define KEY_HCALY "H_CAL_Y"//Run time baseline noise data sent at start of session
//#define KEY_HCALZ "H_CAL_Z"//Run time baseline noise data sent at start of session
#define KEY_HNOISE0 "N0" //Run time baseline bias data set at start of session
#define KEY_HNOISE1 "N1" //Run time baseline bias data set at start of session
#define KEY_HNOISE2 "N2" //Run time baseline bias data set at start of session

#define KEY_SRVCHECK "CHK"//Periodic message sent with this queries server to ensure its still active
#define KEY_SRVOK "OK"//Response from server expected from SRVCHECK
#define KEY_SESSIONID "ID"//This key is the session id
#define KEY_REALSTART "S"//Micros() of packet sampling start
#define KEY_REALSTOP "E"//Micros() of packet sampling end

#define KEY_NUMHALLSENSORS "NumSens"//Number of sensors on maze unit
#define KEY_HALLBLOCKSIZE "HBS" //Block size of Hall sensor data
#define KEY_HALLHASZ "HallHasZ" //Tell server we can provide Hall Z data if desired
#define KEY_ACCELBLOCKSIZE "ABS" //Block size of Accel sensor data

//Server sets these parameters during session start
#define KEY_SENDHZ "WantHZ" //Server session start message will send this key with 0 = no Z, 1 = send Z
#define KEY_SENDSTS "STS" //Server session start reply, 1 = send sample start/end times, 0 = don't send
#define KEY_ACCELSAMPLETIME "AST" //Session start reply sends this key with sample time in ms for Accelerometer
#define KEY_HALLSAMPLETIME "HST"  //Session start reply sends this key with sample time in ms for Hall sensor matrix
#define KEY_HALLMASIZE "HMS" //Session start reply sends this key with # of samples in ring buffer used for moving average of hall sensors
#define KEY_HALLREPORTTIME "HRT" //Session start reply sends this key with how often we report the hall sensor MAfiltered output
#define KEY_SESSIONPORT "PORT"
//see HALLAVERAGINGSAMPLES_MAX above

//I2C Device Addresses
#define OLED_I2C_ADDRESS 0x3C
#define ACCEL_ADDRESS 0x19

//This is the power up addresses of the sensors when using the voltage divider inputs to ADR0/1
//Repeated for convenience across 2 channels
const uint8_t FactoryPowerUpAddresses[NUMSENSORS] = {96,97,98,99,100,101,102,103,104,105,106,107,96,97,98,99,100,101,102,103,104,105,106,107};

//Addresses of hall sensors if they have been programmed
const uint8_t sensorAddresses[] = {12,22,11,21,14,24,13,23,16,26,15,25,32,42,31,41,34,44,33,43,36,46,35,45};
const uint8_t calSensorAddress = 31;
const uint8_t calSensorIndexLocation = 14;//Location in the array above...used to reference sensor data for BiotSavart Const Calculation
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

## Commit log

2022-03-18 Fixed Readme for PCBs
2022-03-18 Reset AllPaths Directory
    [ALLPATHS.csv, ALLPATHS1.csv, Accel1.csv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]
2022-03-19 Fixed duplicates
    [Stylus Cap.stl, Stylus insert.stl, Stylus3.stl]
2022-06-03 Further Server/PacketSimulator Development
    Server:
    Added activesession tracking based on IP. A missed "Bye" from a client will automatically be closed out by the next "Hello" from the client.
    Added graceful shutdown from keyboard interrupt.
    Added db file presence detect and rebuild as needed.
    PacketSimulator
    Added graceful exit from keyboard interrupt (sends "Bye")
2022-06-06 More Server Application Work
    -Saves settings as JSON config file
    -Saves each session in unique db file within RawData folder
    -Some file presence error handling added
    -Hall data now writes to SQL database, currently in row heavy format, may want to consider switch to column heavy format!
    -Accel data write to SQL DB is WIP, see endpoint note in code.
    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
2022-06-09 End of Day Commit - Making ESP32 firmware build again....
    Cant use MCPWM peripherals or code as the register names changed in ESPIDF 4.4.0
2022-06-10 Addition of previously developed experimental firmware
    Threaded firmware, No-Z, Truncated floats etc.....still needs major work for MSGPACK
    Also has basic OLED library and setup routines now added.
2022-06-10 ESP32 Firmware OLED feature enhancement and other UDP work
2022-06-14 EndOfDay Commits
    ESP32 Firmware has majority of setup routine complete.
    Listens for broadcast from server to get IP address & port number. Also confirms service type offered as well as version number.
    UDPSERVER-brkn.py has unfinished modifications which were being used to figure out service broadcast and other features.
    brdcast.py is the service broadcaster for the maze server. This can be integrated later but right now is a standalone program.
    brdcast_client.py just watches upd broadcast packets and spams out some info to the console.
2022-06-16 June 16 EOD Commit
    ESP32 <--> Server Handshaking almost complete.
2022-06-20 End of Weekend Commit
    ESP32 now fully UDP.
    Server App message size added (to help facilitate buffer tuning on ESP32)
2022-06-21 ESP32 Firmware Improvements
    ESP32:
    -Switch from vTaskDelay to xTaskDelayUntil
    -Partial Tuning of Static JSON DOC sizes
    -Added S and E tags showing micros() at packet start/completion
    -Some bug fixes with brdcast.py service announce interval setting
    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
    [main.cpp]
2022-06-22 More ESP32 Tuning/Refactoring/Cleanup (June 22/2022 Commit)
    Removed some deadcode
    Removed some unused variables (holdovers from previous version)
    Tuned some delays
    reAdded HallZ buffer and capture into firmware *** Usage to be determined by server configuration when sending hello
    HallDoc uses nearly 15KB!!!!!
    (Minor change to server to spam out packets while investigating halldoc stuff)
2022-06-27 June 27/2022 EoD Commit
    Tuning work: Stack Sizes of tasks, oled related things.
    Added "spinner" task to indicate session in progress.
    ESP32 now checks response from server at session start for whether the server wants the Hall Z data sent or not and then sends or does not. (This avoids having to recompile ALL THE TIME to test things going forward)
    Still need to add sample time parameter recovery from Server session Start Response
    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
    [main.cpp]
2022-06-28 June28/2022 EOD Commit
    Worked on reducing sample rate jitter of Hall Matrix
    Marginally successful using shorter/longer waits as calculated when a packet is finished.....See code note regarding splitting hallSampleTask into 3 parts.
2022-06-29 June 29/2022 Mid-Day Comitt
    Hall Sampling split into 3 tasks, this was the perfect solution to sample jitter
    Uses Mutexes to synchronize read/writes to common items
    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
    [main.cpp]
2022-06-29 June29/2022 -EOD Commit
    -Moved to single (and larger) arrays for x, y, z values. Instead of x0,x1,.... is now just x and the 24th entry is the 0'th sensor for the next time stamp
    -Change to accomodate single arrays for x,y,z values
    -Started to move from row heavy (many small entries) to column heavy (one large entry) for SQL access - Should be faster for both storage and retrieval later.
    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
2022-07-05 July 4 EOD Commit
    Many Changes to Server Code:
    Move to KEYs being defined in external file to enable sharing formats between programs
    SQL Table Generator no works on NumHallSensors for Hall data
    Logic Improvements
    Move to sessionObject that contains all relevant session information including SQL DB Connection, start and stop times and all the parameters
    Minor changes to code to in places to help with clarity and server changes above.
    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
2022-07-13 July 12 EOD Commit
    Some major edits applied since last commit.
    -Threaded, now launches a new thread to handle each session.
    -Sessions are marked completed as they are closed by the session thread, and then signals a handler to launch processing of the data
    -Keyboard watch thread, monitors keyboard input to allow graceful exits, and turning on verbosity.
    -Minor edits to accommodate difference in session initiator and session specific thread UDP ports.
    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
2022-07-18 Major Server Improvements
    Server threading now working as intended.
    Server shutdown more graceful.
    Server run time keypress toggles now using non blocking input.
2022-08-02 August 2/2022 EOD Commit
    See Teams log for details. Things are broken!
    [main.cpp]
2022-08-22 UDPServer now handles Multi Hall Calibration data
    Server updated to unpack and store the new multi calibration data. Digest still not updated.
2022-08-24 UDPSERVER bug
    Hall data is not being processed correctly. A set of values seems to be copied to each time step and the values do not seem to line up with the sensor outputs as expected as seen in the wireshark capture...
2022-09-09 Hall data unpack fixed! Digest showing results
    Hall data unpacking is now working correctly, the remaining issue was forgetting the timestamp increment offset.
    Digest application temporarily set to use the first of 3 snapshots for BSC and Noise data. Showing results though!
